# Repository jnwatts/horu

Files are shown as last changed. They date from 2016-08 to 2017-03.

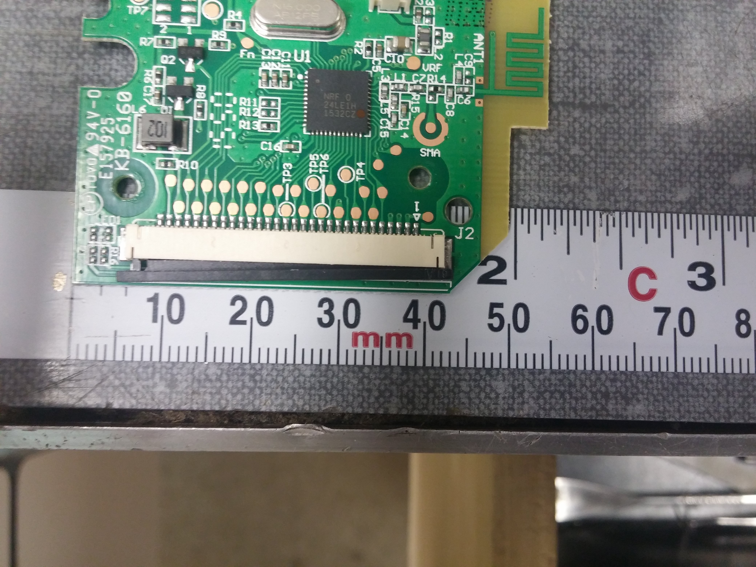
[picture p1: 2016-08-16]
photos/IMG_20160808_184751.jpg

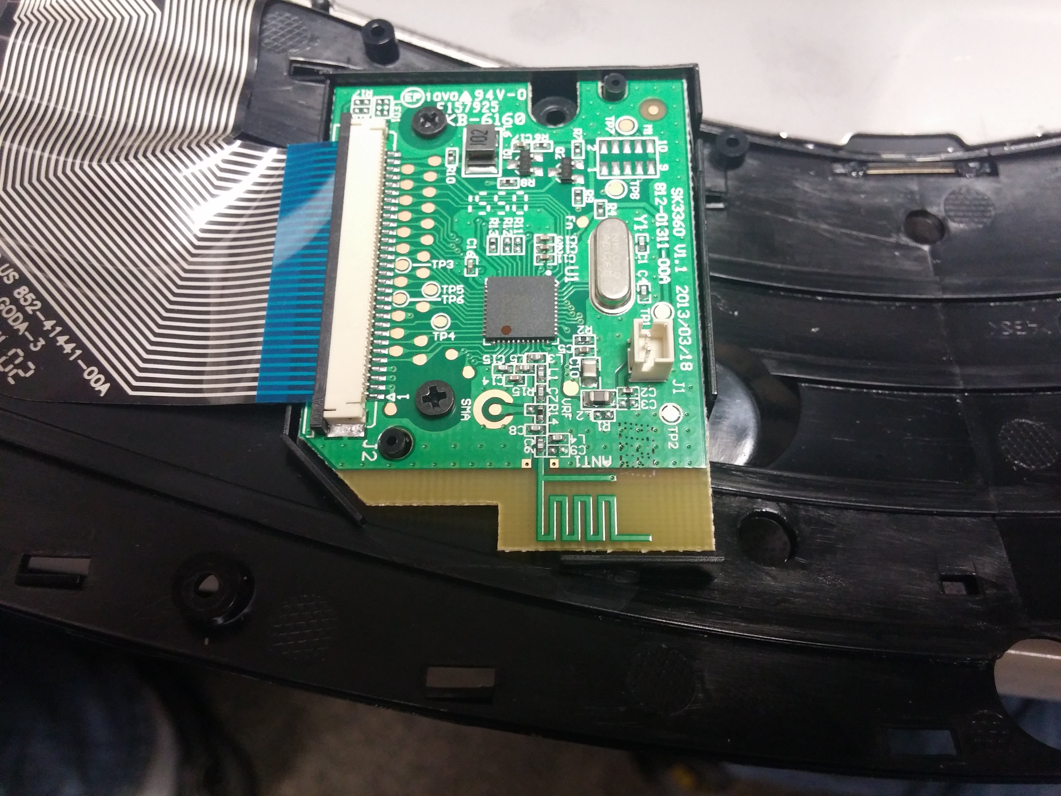
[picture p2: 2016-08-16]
photos/IMG_20160808_184125.jpg

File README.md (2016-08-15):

# What
Replacement logic board and firmware for Micro$oft's Sculpt keyboard

# Why
I really quite like M$'s line of ergonomic keyboards, most recently the Sculpt. Unlike the previous models I've enjoyed, the Sculpt has only a wireless model. While very slick, I'm somewhat concerned about the recent [MouseJack](https://www.mousejack.com/) revelations. From what I've read, my typed data should still be (reasonably) secure, but M$ has yet to announce updated FW for the USB dongle which could allow anyone in range to inject malicious HID packets to my machine. Maybe it's simply impossible to update the FW on the dongle?

# How
To "resolve" this security issue, this project will produce a logic board and firmware to convert the Sculpt to a normal USB keyboard. Currently, I only plan to convert the main keybaord and ignore the floating 10-key device, and I neither have nor care about the associated mouse.

# When
There's no particular time-scale for this project, except that I am already using the Sculpt in it's original state: I'm hoping to develop this board and working firmware before one of my colleages manages to take over my PC with an SDR or something. ;-)

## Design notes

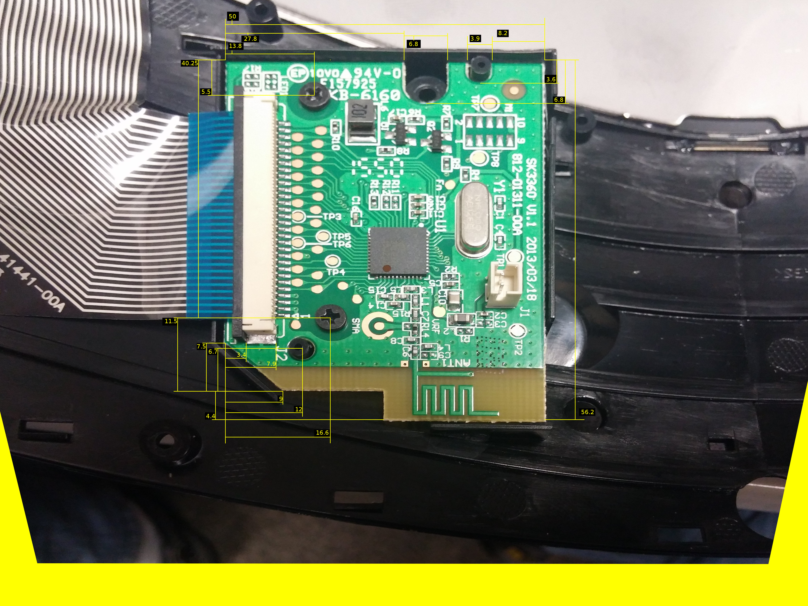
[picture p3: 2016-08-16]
photos/IMG_20160808_184125_dimensions.jpg

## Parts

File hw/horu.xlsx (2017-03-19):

 |  |  |  |  |  |  | Board Qty: | 3
 |  |  |  |  |  |  | Total Cost: | $35.79 |  |  |  | $38.83
 |  |  |  |  |  |  | Unit Cost: | $11.93
Global Part Info |  |  |  |  |  |  |  |  | Mouser
Refs | Value | Desc | Footprint | Manf | Manf# | Qty | Unit$ | Ext$ | Avail | Purch | Unit$ | Ext$ | Cat# | Doc
Y1 | 8MHz |  | Crystals:Crystal_SMD_Abracon_ABM3B-4pin_5.0x3.2mm |  | ABM3B-8.000MHZ-B2-T | 3 | $0.65 | $1.95 | 3870 | 3 | $0.65 | $1.95 | 815-ABM3B-8.0-B2-T | Link (http://www.mouser.com/Search/Refine.aspx?Keyword=ABM3B-8.000MHZ-B2-T%20)
C2,C3 | 22 pF |  | Resistors_SMD:R_0603_HandSoldering |  | GRM1885C1H220JA01D | 6 | $0.02 | $0.13 | 180907 | 10 | $0.02 | $0.22 | 81-GRM39C220J50 | Link (http://www.mouser.com/Search/Refine.aspx?Keyword=GRM1885C1H220JA01D%20)
U1 | KL25P80M48SF0 |  | horu:LQFP-80_12x12mm_Pitch0.5mm |  | MKL25Z128VLK4 | 3 | $6.47 | $19.41 | 573 | 3 | $6.47 | $19.41 | 841-MKL25Z128VLK4 | Link (http://www.mouser.com/ProductDetail/NXP-Freescale/MKL25Z128VLK4/?qs=sGAEpiMZZMuWgNZUrZaZjJzDCqOusTwq)
C6 | 2.2 uF |  | Resistors_SMD:R_0603_HandSoldering |  | GRM188R61C225KE15D | 3 | $0.05 | $0.16 | 288205 | 10 | $0.05 | $0.52 | 81-GRM188R61C225KE15 | Link (http://www.mouser.com/Search/Refine.aspx?Keyword=GRM188R61C225KE15D%20)
R7 | 0 |  | Resistors_SMD:R_0402 |  | ERJ-3GEY0R00V | 3 | $0.01 | $0.04 | 1071823 | 10 | $0.01 | $0.12 | 667-ERJ-3GEY0R00V | Link (http://www.mouser.com/Search/Refine.aspx?Keyword=ERJ-3GEY0R00V%20)
C1,C4,C5 | 1.0 uF |  | Resistors_SMD:R_0603_HandSoldering |  | GRM188R61C105KA93D | 9 | $0.02 | $0.19 | 259679 | 10 | $0.02 | $0.21 | 81-GRM39R105K16 | Link (http://www.mouser.com/Search/Refine.aspx?Keyword=GRM188R61C105KA93D%20)
P5 | CONN_02X05 |  | Pin_Headers:Pin_Header_Straight_2x05_Pitch1.27mm_SMD |  | 20021121-00010C4LF | 3 | $0.80 | $2.40 | 12614 | 3 | $0.80 | $2.40 | 649-202112100010C4LF | Link (http://www.mouser.com/Search/Refine.aspx?Keyword=20021121-00010C4LF%20)
D1-D4 | LED_GREEN |  | LEDs:LED_0603 |  | LG Q396-PS-35 | 12 | $0.22 | $2.62 | 32953 | 12 | $0.22 | $2.62 | 720-LGQ396A3964 | Link (http://www.mouser.com/Search/Refine.aspx?Keyword=LG%20Q396-PS-35%20)
R1-R4 | 220 |  | Resistors_SMD:R_0603_HandSoldering |  | ERJ-3GEYJ221V | 12 | $0.01 | $0.14 | 118877 | 12 | $0.01 | $0.14 | 667-ERJ-3GEYJ221V | Link (http://www.mouser.com/Search/Refine.aspx?Keyword=ERJ-3GEYJ221V%20)
TP1-TP4 | TEST_1P |  | Measurement_Points:Measurement_Point_Round-TH_Small |  |  | 12 | $0.00 | $0.00
R5,R6 | 33 |  | Resistors_SMD:R_0603_HandSoldering |  | ERJ-3GEYJ330V | 6 | $0.01 | $0.08 | 167981 | 10 | $0.01 | $0.13 | 667-ERJ-3GEYJ330V | Link (http://www.mouser.com/Search/Refine.aspx?Keyword=ERJ-3GEYJ330V%20)
P3 | CONN_01X30_2SHIELD |  | horu:52271-3079 |  | 52271-3079 | 3 | $1.98 | $5.94 | 935 | 3 | $1.98 | $5.94 | 538-52271-3079 | Link (http://www.mouser.com/Search/Refine.aspx?Keyword=52271-3079%20)
L1,L2 | 330 Ohm |  | Resistors_SMD:R_0603_HandSoldering |  | BLM18SG331TN1D | 6 | $0.07 | $0.45 | 75638 | 10 | $0.07 | $0.75 | 81-BLM18SG331TN1D | Link (http://www.mouser.com/Search/Refine.aspx?Keyword=BLM18SG331TN1D%20)
P2 | DNP |  | Connectors:USB_Micro-B |  |  | 3 | $0.00 | $0.00
P1,P4 | CONN_01X06 |  | horu:PINHEAD1-6 |  | 4-103327-6 | 6 | $0.23 | $1.38 | 7837 |  | $0.23 | $1.38 | 571-4-103327-6 | Link (http://www.mouser.com/Search/Refine.aspx?Keyword=4-103327-6%20)
R8 | 10k |  | Resistors_SMD:R_0603_HandSoldering |  | ERJ-3GEYJ103V | 3 | $0.01 | $0.04 | 741819 | 10 | $0.01 | $0.12 | 667-ERJ-3GEYJ103V | Link (http://www.mouser.com/Search/Refine.aspx?Keyword=ERJ-3GEYJ103V%20)
JP101 | Jumper_NC_Dual |  | Connectors:GS3 |  |  | 3 | $0.00 | $0.00
D5 | D_Zener_x2_ACom_KKA |  | TO_SOT_Packages_SMD:SOT-23 |  | GSOT05C-G3-08 | 3 | $0.29 | $0.88 | 8761 | 10 | $0.29 | $2.92 | 78-GSOT05C-G3-08 | Link (http://www.mouser.com/ProductDetail/Vishay-Semiconductors/GSOT05C-G3-08/)
 |  |  |  |  |  |  |  |  |  | 815-ABM3B-8.0-B2-T | 3 | Y1
 |  |  |  |  |  |  |  |  |  | 81-GRM39C220J50 | 10 | C2,C3
 |  |  |  |  |  |  |  |  |  | 841-MKL25Z128VLK4 | 3 | U1
 |  |  |  |  |  |  |  |  |  | 81-GRM188R61C225KE15 | 10 | C6
 |  |  |  |  |  |  |  |  |  | 667-ERJ-3GEY0R00V | 10 | R7
 |  |  |  |  |  |  |  |  |  | 81-GRM39R105K16 | 10 | C1,C4,C5
 |  |  |  |  |  |  |  |  |  | 649-202112100010C4LF | 3 | P5
 |  |  |  |  |  |  |  |  |  | 720-LGQ396A3964 | 12 | D1-D4
 |  |  |  |  |  |  |  |  |  | 667-ERJ-3GEYJ221V | 12 | R1-R4
 |  |  |  |  |  |  |  |  |  | 667-ERJ-3GEYJ330V | 10 | R5,R6
 |  |  |  |  |  |  |  |  |  | 538-52271-3079 | 3 | P3
 |  |  |  |  |  |  |  |  |  | 81-BLM18SG331TN1D | 10 | L1,L2
 |  |  |  |  |  |  |  |  |  | 667-ERJ-3GEYJ103V | 10 | R8
 |  |  |  |  |  |  |  |  |  | 78-GSOT05C-G3-08 | 10 | D5

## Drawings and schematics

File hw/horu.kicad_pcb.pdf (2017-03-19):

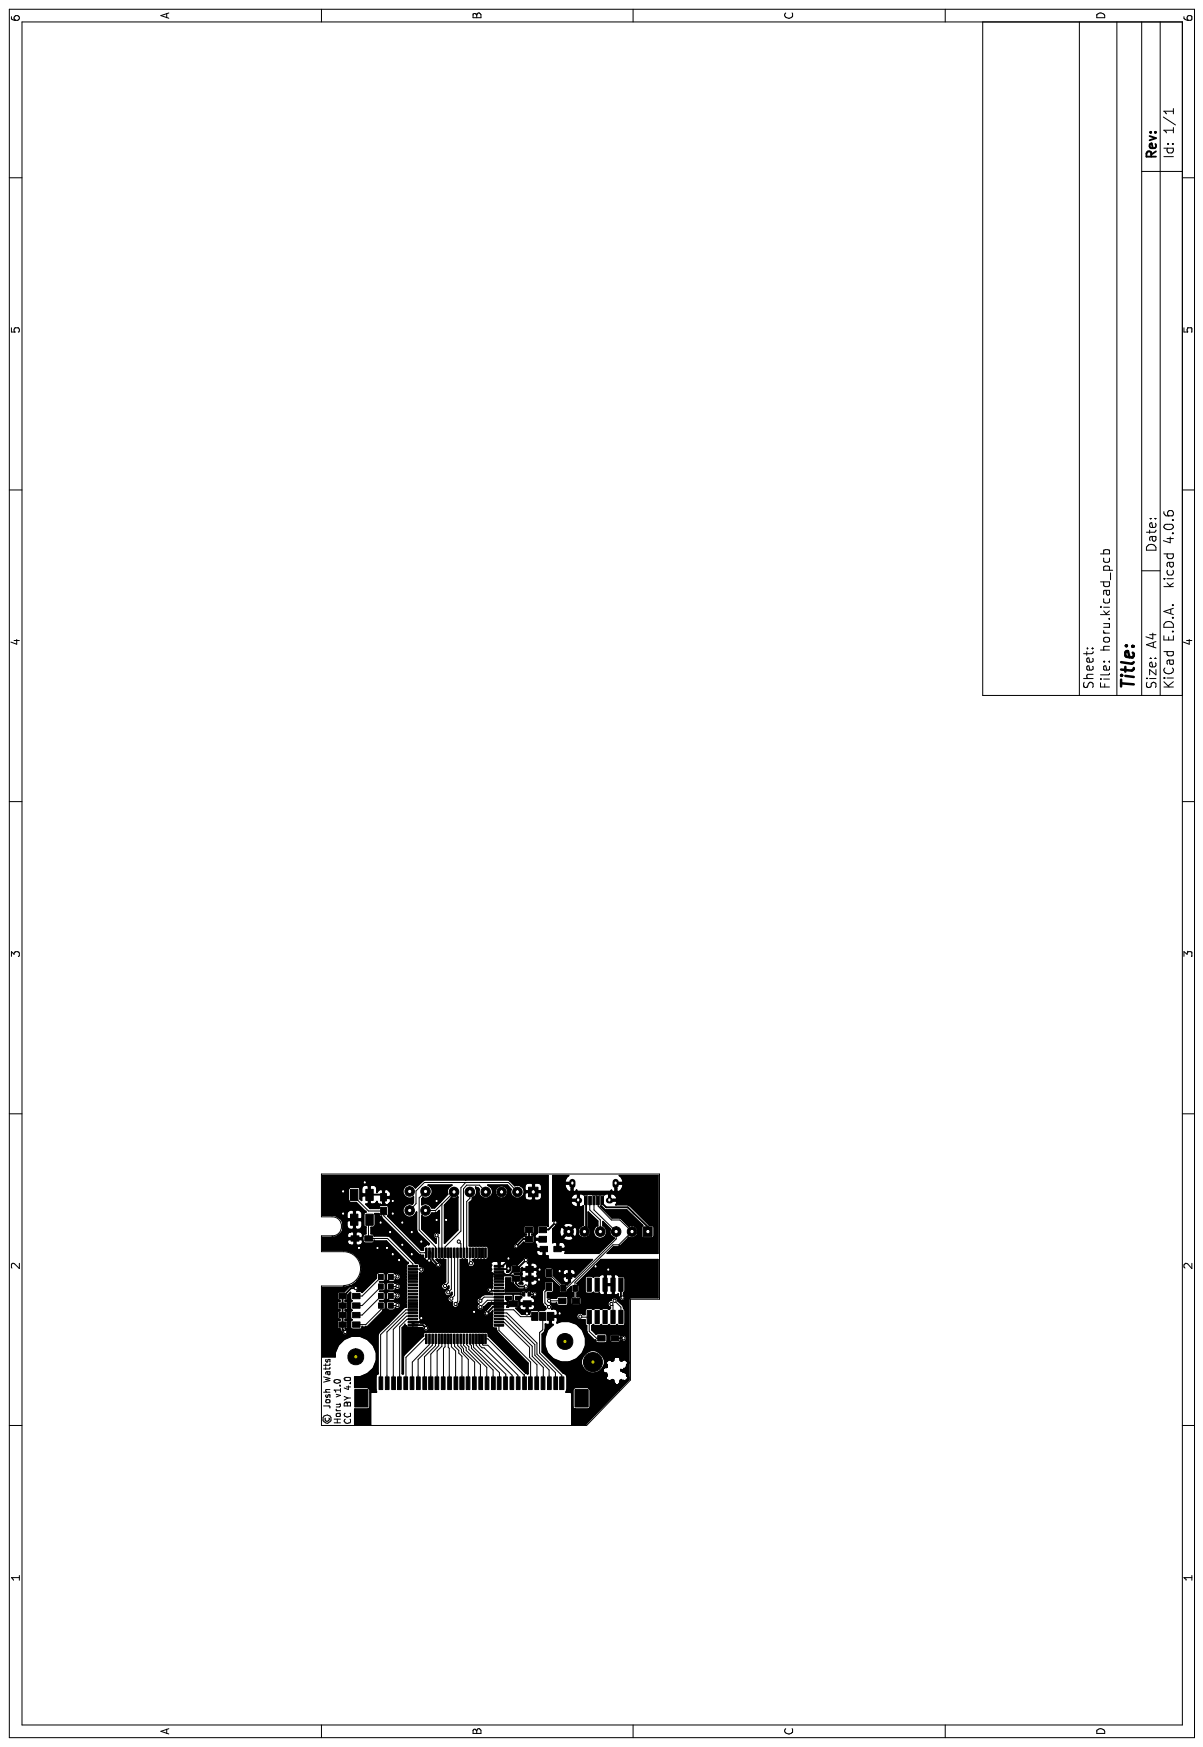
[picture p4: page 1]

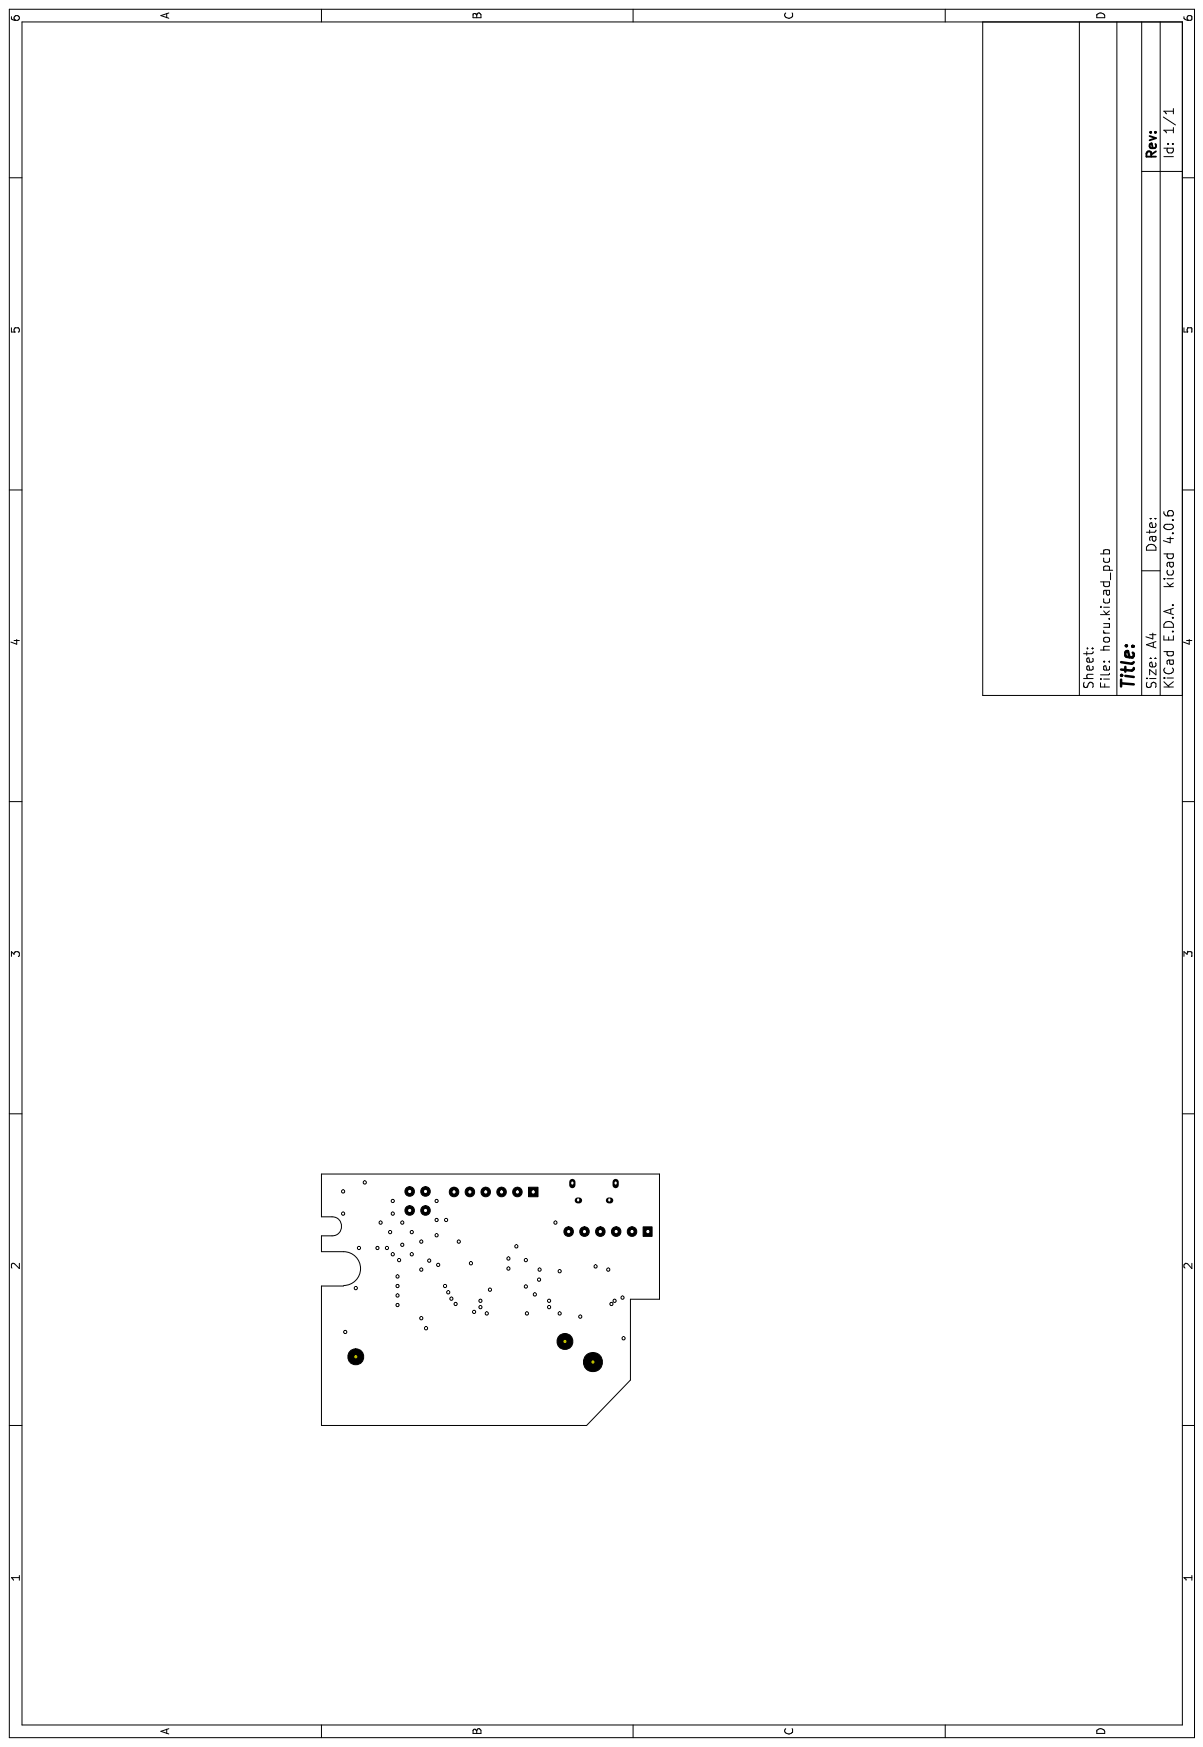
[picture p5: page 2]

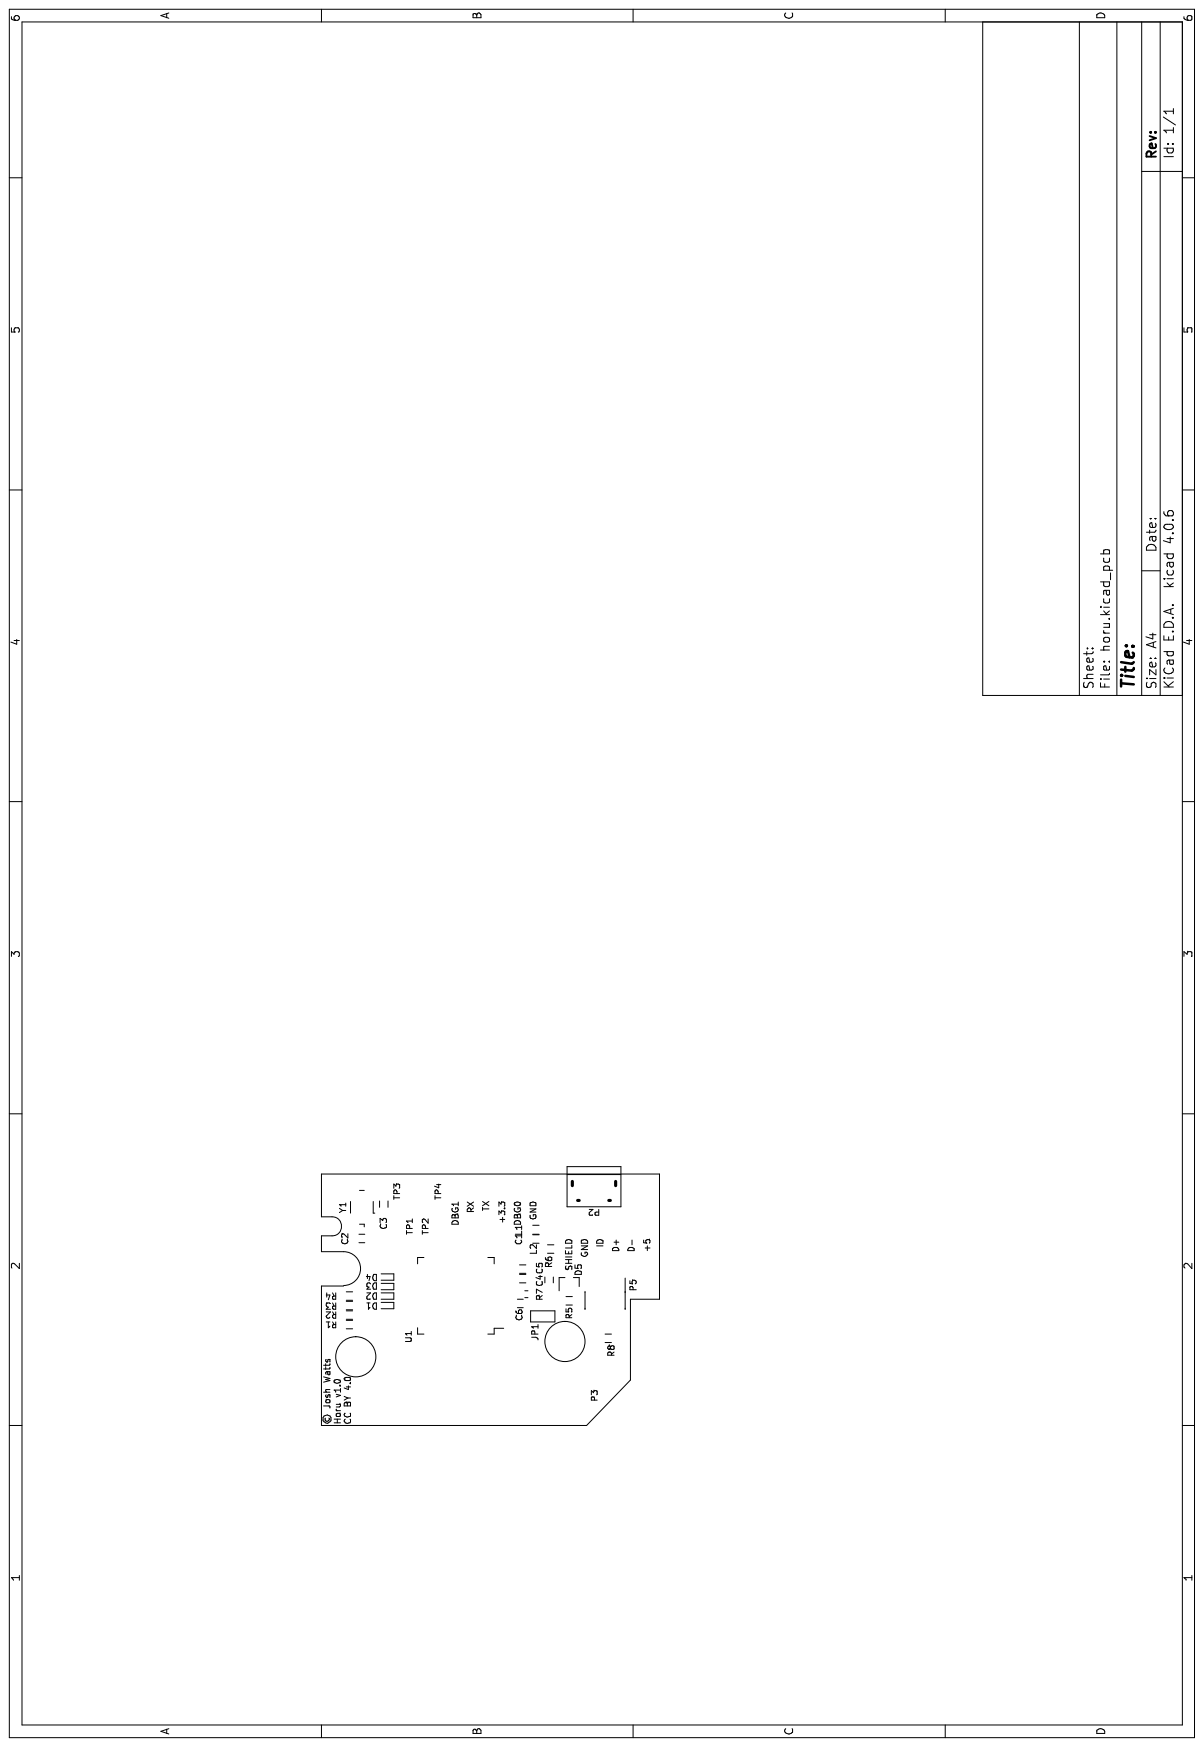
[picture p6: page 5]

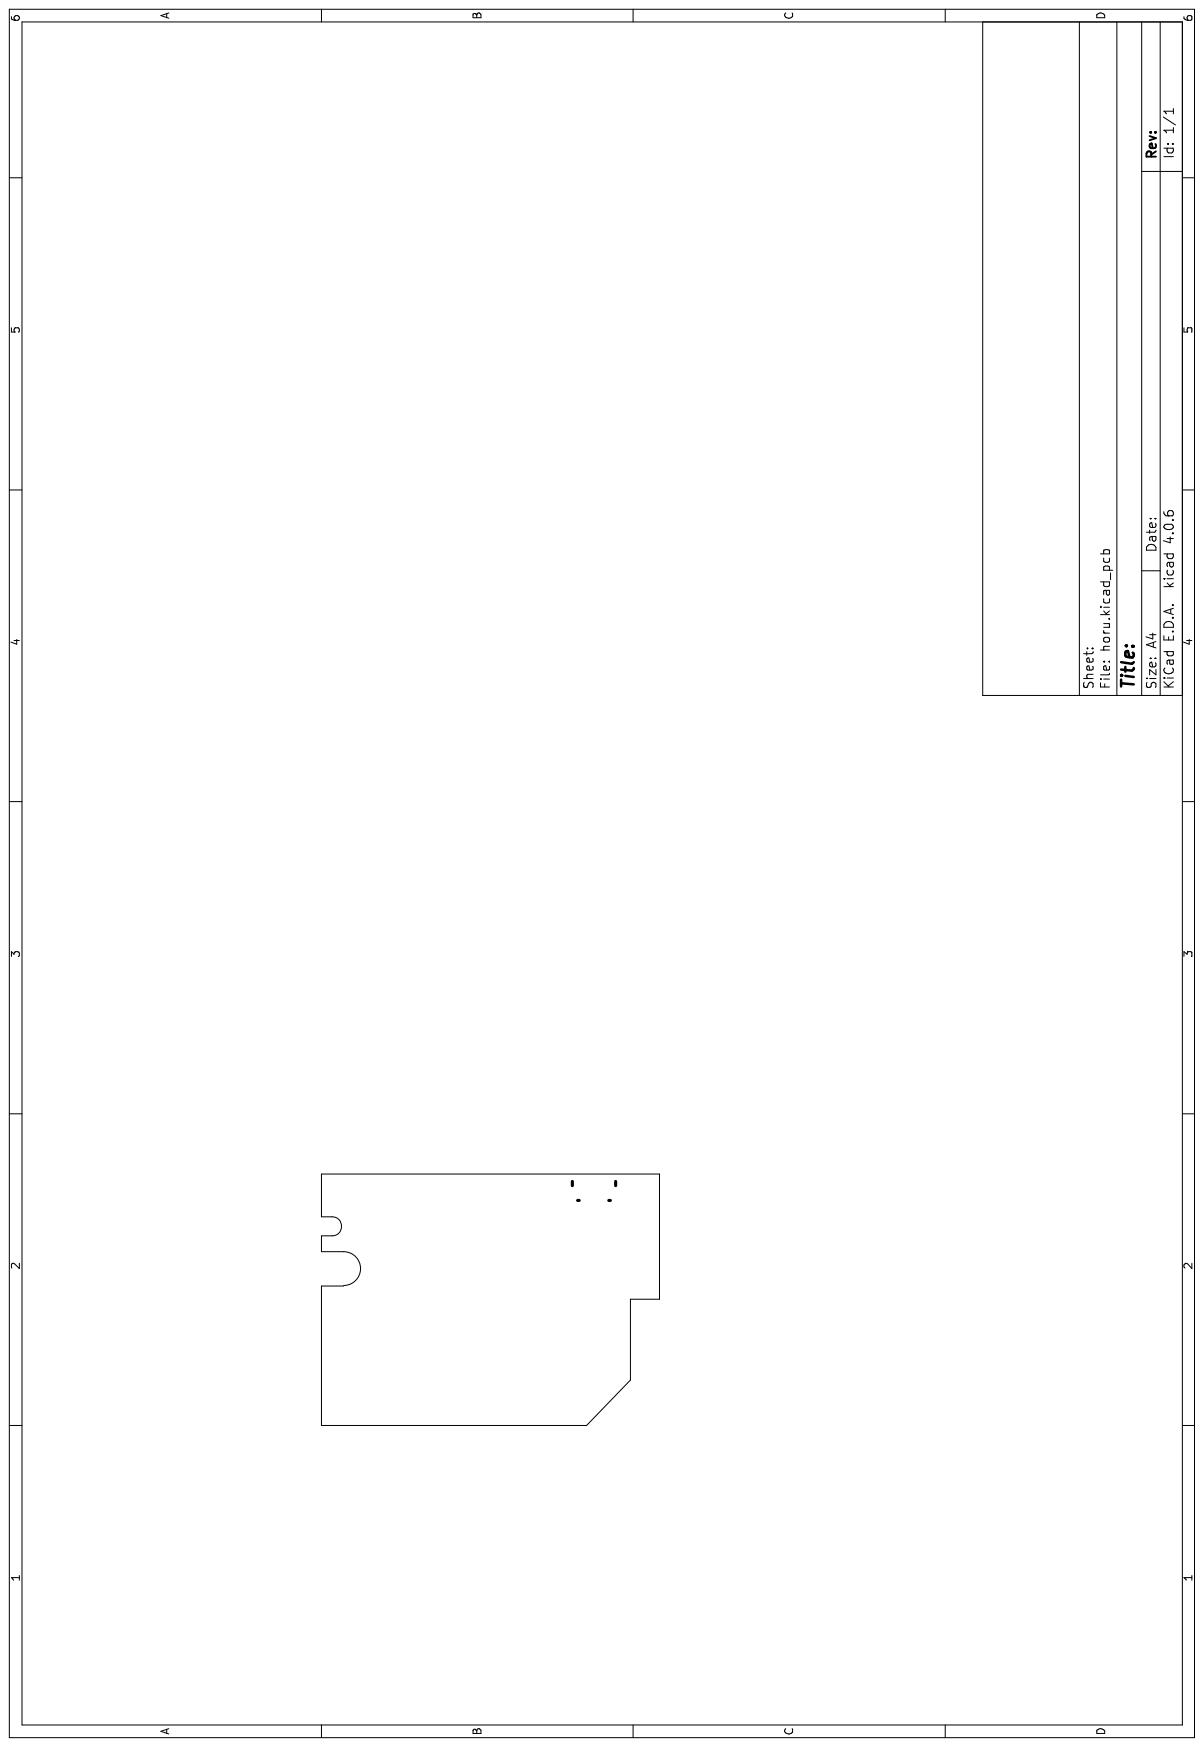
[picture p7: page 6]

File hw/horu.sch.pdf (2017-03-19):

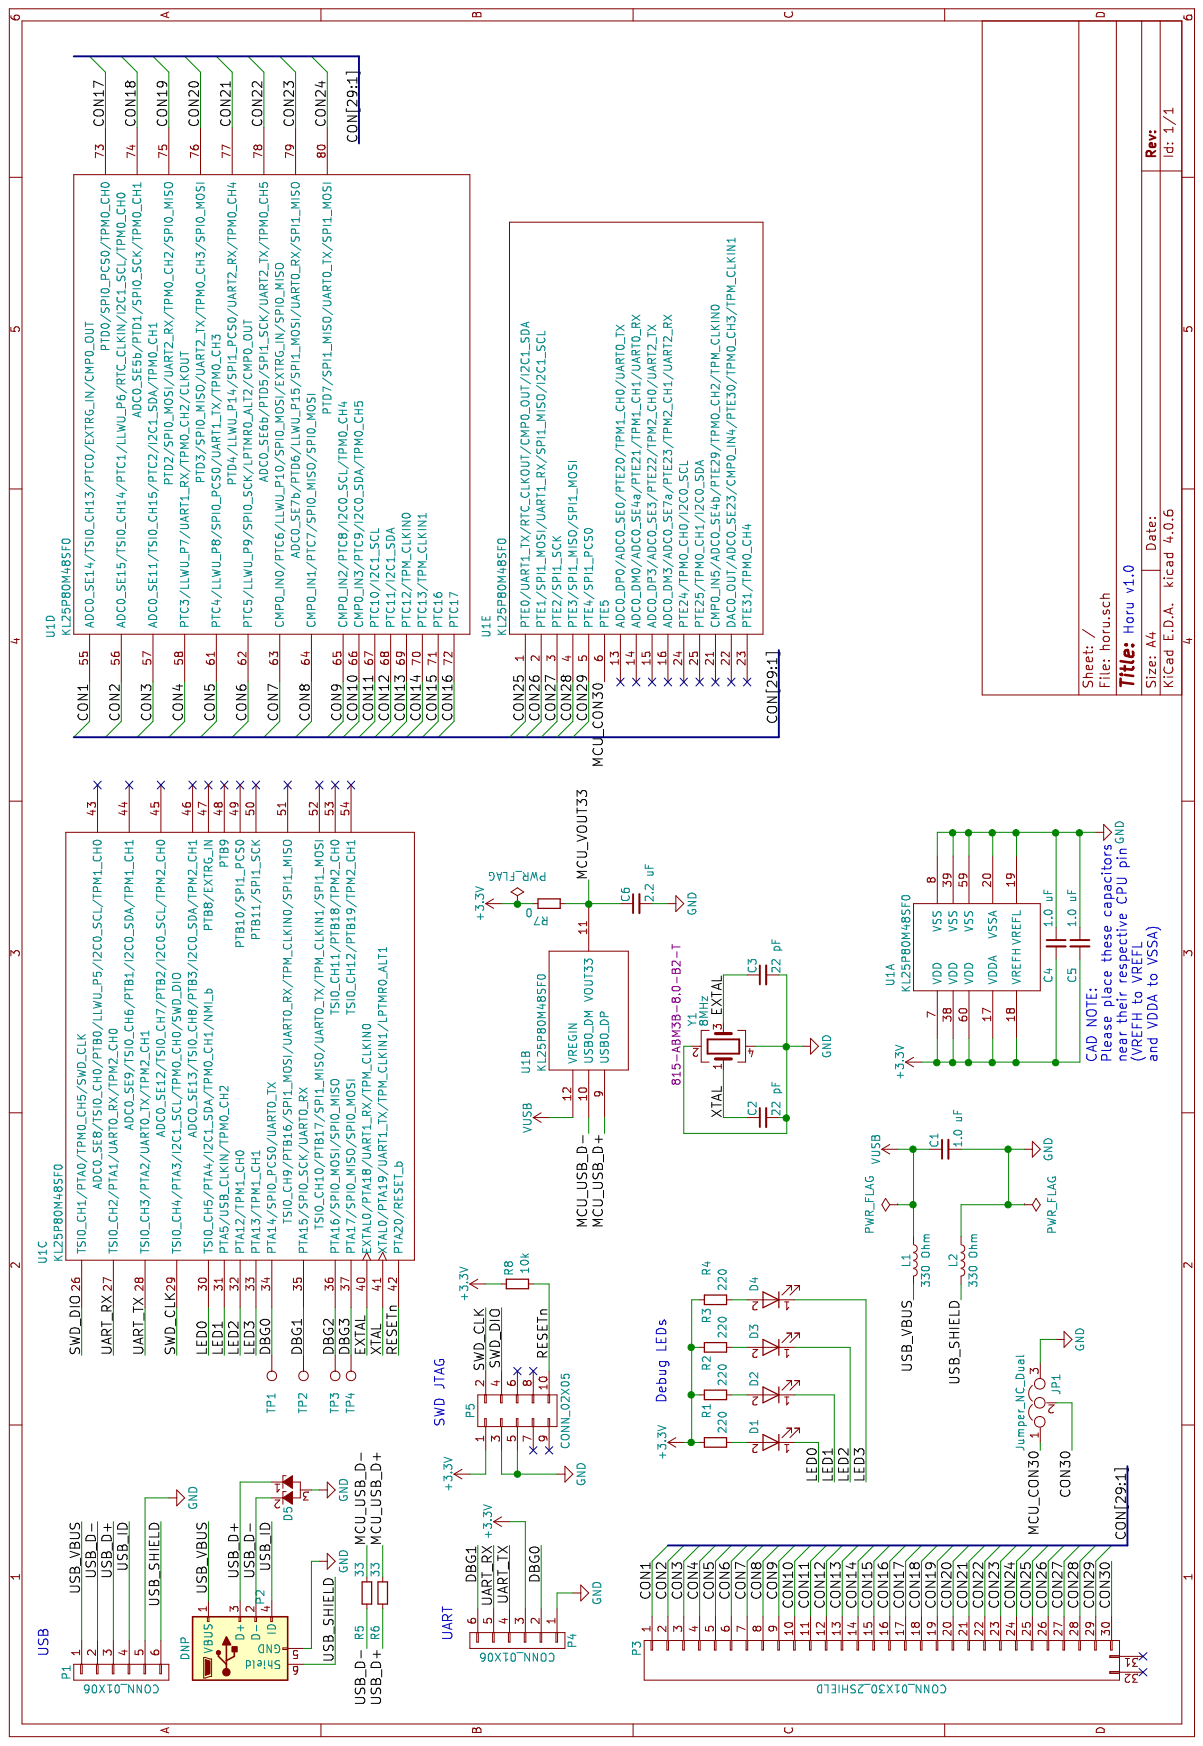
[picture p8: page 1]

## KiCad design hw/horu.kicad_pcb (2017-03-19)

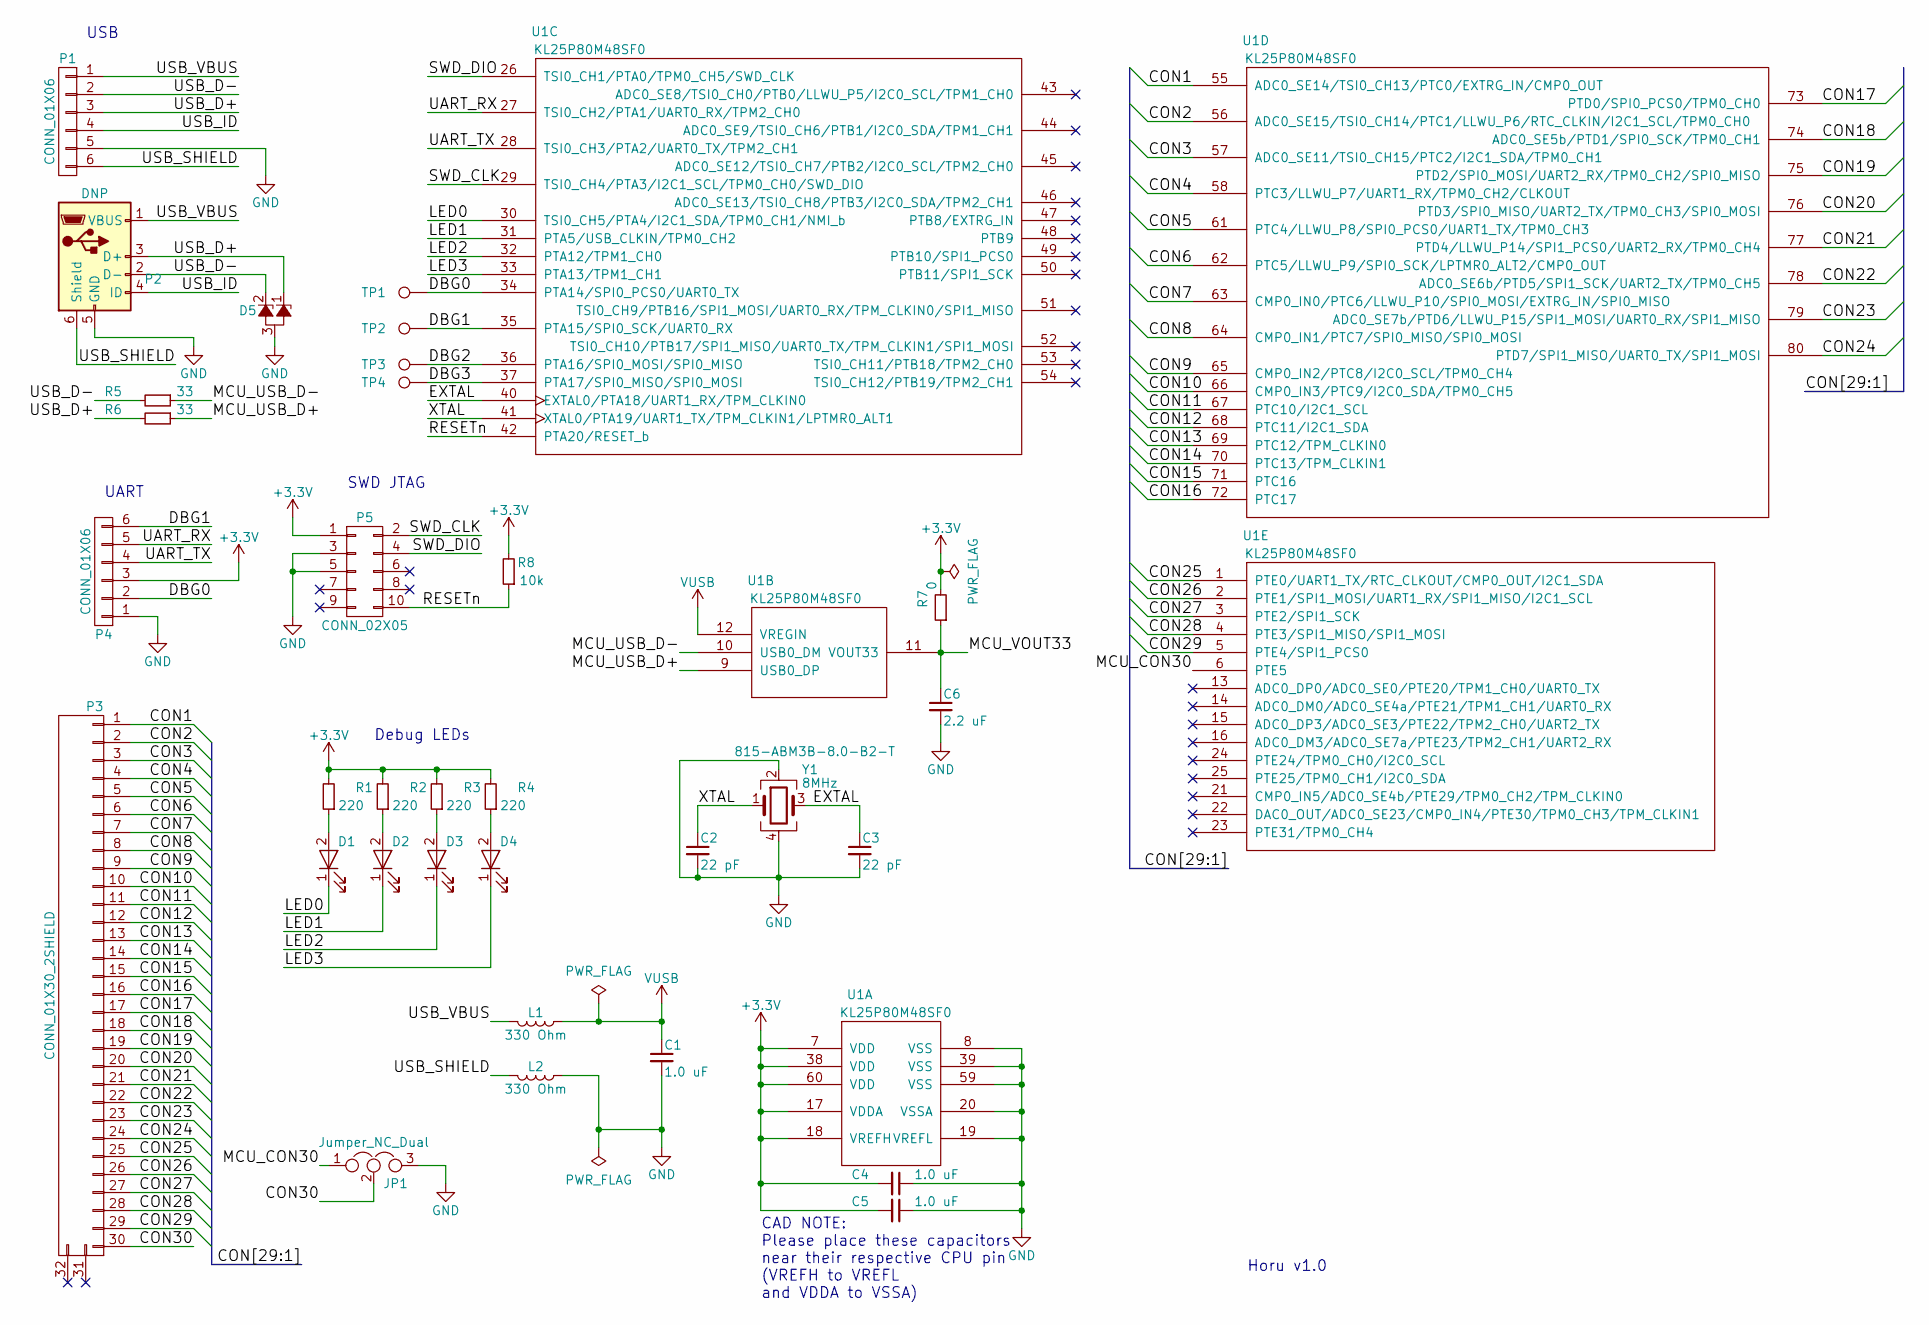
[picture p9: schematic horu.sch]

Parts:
C1, C4, C5: 1.0 uF; R_0603_HandSoldering
C2, C3: 22 pF; R_0603_HandSoldering
C6: 2.2 uF; R_0603_HandSoldering
D1, D2, D3, D4: LED_GREEN; LED_0603
D5: D_Zener_x2_ACom_KKA; SOT-23
JP1: Jumper_NC_Dual; GS3
L1, L2: 330 Ohm; R_0603_HandSoldering
P1, P4: CONN_01X06; PINHEAD1-6
P2: DNP; USB_Micro-B
P3: CONN_01X30_2SHIELD; 52271-3079
P5: CONN_02X05; Pin_Header_Straight_2x05_Pitch1.27mm_SMD
R1, R2, R3, R4: 220; R_0603_HandSoldering
R5, R6: 33; R_0603_HandSoldering
R7: 0; R_0402
R8: 10k; R_0603_HandSoldering
TP1, TP2, TP3, TP4: TEST_1P; Measurement_Point_Round-TH_Small
U1: KL25P80M48SF0; LQFP-80_12x12mm_Pitch0.5mm
Y1: 8MHz; Crystal_SMD_Abracon_ABM3B-4pin_5.0x3.2mm

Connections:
+3V3_SDA: C4.2, C5.2, P4.3, P5.1, R1.2, R2.2, R3.2, R4.2, R7.2, R8.2, U1.7 (VDD), U1.17 (VDDA), U1.18 (VREFH), U1.38 (VDD), U1.60 (VDD)
/CON1: P3.1, U1.55 (ADC0_SE14/TSI0_CH13/PTC0/EXTRG_IN/CMP0_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)
/CON2: P3.2, U1.56 (ADC0_SE15/TSI0_CH14/PTC1/LLWU_P6/RTC_CL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)
/CON3: P3.3, U1.57 (ADC0_SE11/TSI0_CH15/PTC2/I2C1_SDA/TPM0_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)
/CON4: P3.4, U1.58 (PTC3/LLWU_P7/UART1_RX/TPM0_CH2/CLKOUT)
/CON5: P3.5, U1.61 (PTC4/LLWU_P8/SPI0_PCS0/UART1_TX/TPM0_CH3)
/CON6: P3.6, U1.62 (PTC5/LLWU_P9/SPI0_SCK/LPTMR0_ALT2/CMP0_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)
/CON7: P3.7, U1.63 (CMP0_IN0/PTC6/LLWU_P10/SPI0_MOSI/EXTRG_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)
/CON8: P3.8, U1.64 (CMP0_IN1/PTC7/SPI0_MISO/SPI0_MOSI)
/CON9: P3.9, U1.65 (CMP0_IN2/PTC8/I2C0_SCL/TPM0_CH4)
/CON10: P3.10, U1.66 (CMP0_IN3/PTC9/I2C0_SDA/TPM0_CH5)
/CON11: P3.11, U1.67 (PTC10/I2C1_SCL)
/CON12: P3.12, U1.68 (PTC11/I2C1_SDA)
/CON13: P3.13, U1.69 (PTC12/TPM_CLKIN0)
/CON14: P3.14, U1.70 (PTC13/TPM_CLKIN1)
/CON15: P3.15, U1.71 (PTC16)
/CON16: P3.16, U1.72 (PTC17)
/CON17: P3.17, U1.73 (PTD0/SPI0_PCS0/TPM0_CH0)
/CON18: P3.18, U1.74 (ADC0_SE5b/PTD1/SPI0_SCK/TPM0_CH1)
/CON19: P3.19, U1.75 (PTD2/SPI0_MOSI/UART2_RX/TPM0_CH2/SPI0_M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)
/CON20: P3.20, U1.76 (PTD3/SPI0_MISO/UART2_TX/TPM0_CH3/SPI0_M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)
/CON21: P3.21, U1.77 (PTD4/LLWU_P14/SPI1_PCS0/UART2_RX/TPM0_C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)
/CON22: P3.22, U1.78 (ADC0_SE6b/PTD5/SPI1_SCK/UART2_TX/TPM0_C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)
/CON23: P3.23, U1.79 (ADC0_SE7b/PTD6/LLWU_P15/SPI1_MOSI/UART0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)
/CON24: P3.24, U1.80 (PTD7/SPI1_MISO/UART0_TX/SPI1_MOSI)
/CON25: P3.25, U1.1 (PTE0/UART1_TX/RTC_CLKOUT/CMP0_OUT/I2C1_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)
/CON26: P3.26, U1.2 (PTE1/SPI1_MOSI/UART1_RX/SPI1_MISO/I2C1_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)
/CON27: P3.27, U1.3 (PTE2/SPI1_SCK)
/CON28: P3.28, U1.4 (PTE3/SPI1_MISO/SPI1_MOSI)
/CON29: P3.29, U1.5 (PTE4/SPI1_PCS0)
/CON30: JP1.2, P3.30
/DBG0: P4.2, TP1.1, U1.34 (PTA14/SPI0_PCS0/UART0_TX)
/DBG1: P4.6, TP2.1, U1.35 (PTA15/SPI0_SCK/UART0_RX)
/DBG2: TP3.1, U1.36 (PTA16/SPI0_MOSI/SPI0_MISO)
/DBG3: TP4.1, U1.37 (PTA17/SPI0_MISO/SPI0_MOSI)
/EXTAL: C3.1, U1.40 (EXTAL0/PTA18/UART1_RX/TPM_CLKIN0), Y1.3
/LED0: D1.1 (K), U1.30 (TSI0_CH5/PTA4/I2C1_SDA/TPM0_CH1/NMI_b)
/LED1: D2.1 (K), U1.31 (PTA5/USB_CLKIN/TPM0_CH2)
/LED2: D3.1 (K), U1.32 (PTA12/TPM1_CH0)
/LED3: D4.1 (K), U1.33 (PTA13/TPM1_CH1)
/MCU_CON30: JP1.1, U1.6 (PTE5)
/MCU_USB_D+: R6.1, U1.9 (USB0_DP)
/MCU_USB_D-: R5.1, U1.10 (USB0_DM)
/MCU_VOUT33: C6.1, R7.1, U1.11 (VOUT33)
/RESETn: P5.10, R8.1, U1.42 (PTA20/RESET_b)
/SWD_CLK: P5.2, U1.29 (TSI0_CH4/PTA3/I2C1_SCL/TPM0_CH0/SWD_DIO)
/SWD_DIO: P5.4, U1.26 (TSI0_CH1/PTA0/TPM0_CH5/SWD_CLK)
/UART_RX: P4.5, U1.27 (TSI0_CH2/PTA1/UART0_RX/TPM2_CH0)
/UART_TX: P4.4, U1.28 (TSI0_CH3/PTA2/UART0_TX/TPM2_CH1)
/USB_D+: D5.1 (K), P1.3, P2.3 (D+), R6.2
/USB_D-: D5.2 (K), P1.2, P2.2 (D-), R5.2
/USB_ID: P1.4, P2.4 (ID)
/USB_SHIELD: L2.2, P1.6, P2.6 (Shield)
/USB_VBUS: L1.2, P1.1, P2.1 (VBUS)
/XTAL: C2.1, U1.41 (XTAL0/PTA19/UART1_TX/TPM_CLKIN1/LPTMR0_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), Y1.1
GND: C1.2, C2.2, C3.2, C4.1, C5.1, C6.2, D5.3 (A), JP1.3, L2.1, P1.5, P2.5 (GND), P4.1, P5.3, P5.5, U1.8 (VSS), U1.19 (VREFL), U1.20 (VSSA), U1.39 (VSS), U1.59 (VSS), Y1.2, Y1.4
unnamed: D1.2 (A), R1.1
unnamed: D2.2 (A), R2.1
unnamed: D3.2 (A), R3.1
unnamed: D4.2 (A), R4.1
VUSB: C1.1, L1.1, U1.12 (VREGIN)

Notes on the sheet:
CAD NOTE: Please place these capacitors near their respective CPU pin (VREFH to VREFL and VDDA to VSSA)
USB
UART
SWD JTAG
Debug LEDs
Horu v1.0

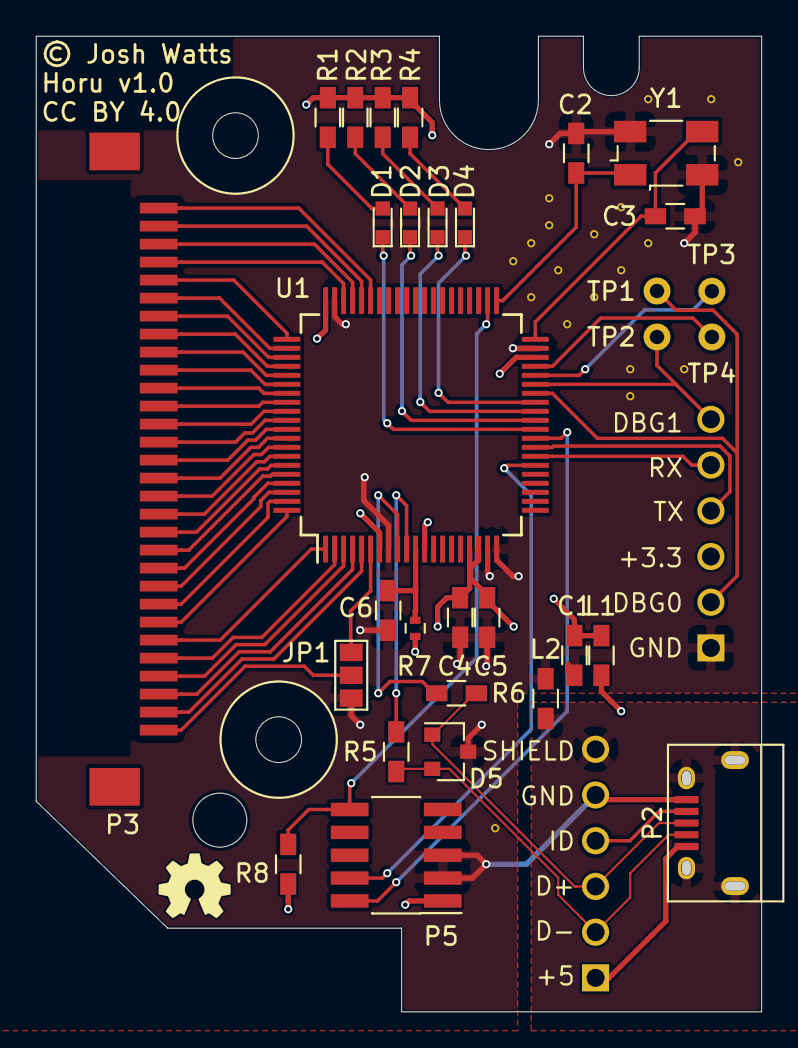
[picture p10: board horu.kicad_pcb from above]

Board: 4 copper layers, 40.3 x 54.2 mm, 33 parts (0 on the bottom side), 61 nets.

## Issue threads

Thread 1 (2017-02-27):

Add stapled ground plane around extal/xtal

jnwatts, 2017-02-27:
Protect these lines from emission and nearby noise

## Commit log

2016-08-16 Add photos of original board
2017-02-05 Initial commit of HW
    * OpenSDA region complete
    * Cleaner KL25 symbol (not yet placed)
    [horu.kicad_pcb, horu.sch, opensda.sch]
2017-02-06 Schematic complete except for decoupling
    [horu.sch, opensda.sch]
2017-02-09 Define some footprints
    [horu.sch, opensda.sch]
2017-02-09 Drop opensda circuit
    This makes room in BOM for fancy USB switch letting either USB-C port be connected to PC, while other can connect (in future) to keypad
    [horu.sch, opensda.sch, usb.sch]
2017-02-09 Add footprint for molex FPC
2017-02-10 Add some more footprints
    [horu.sch, usb.sch]
2017-02-27 Update to v0.1 release
    * Fall back to simple mUSB-B (connector + pigtail supported)
    * First pass at layout
    * Added missing pull-up to RESETn
    [horu.kicad_pcb, horu.sch]
2017-02-28 Changed to copper pour for each layer
    [horu.kicad_pcb, horu.sch]
2017-03-19 Update schematic and prepare for release
    * Update rev to v1.0
    * Update USB_OTG symbol
    * Add missing USB ESD diodes
    * Fill in manf# for all parts
    * Export BOM using kicost
    * Fill ground on bottom layer
    * Replace traces on inner 2 with properly placed vias to allow fill to connect everything
    [horu.kicad_pcb, horu.sch, horu.xlsx]
2017-03-19 Update design
    * Fix JP101 -> JP1
    * Update USB_OTG -> DNP
    [horu.kicad_pcb, horu.sch]
2017-03-19 Rev v1.0
    * Remove not-so-useful release folder
    * Update schematic and layout pdfs
    [horu.xlsx]
2020-01-25 Update to KiCad 5.1.5 & replace EOL capacitors
    [horu.sch]

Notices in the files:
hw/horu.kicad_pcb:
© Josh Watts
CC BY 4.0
